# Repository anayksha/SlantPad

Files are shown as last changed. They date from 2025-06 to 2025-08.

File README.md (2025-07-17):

# SlantPad
So this is a really interesting looking macropad that I will primarily be using to CAD on Onshape.

The most distinctive feature is that the OLED and rotary encoder are mounted on the front at an angle
and will be attached to the PCB by soldering wires from the PCB to the components.

**Note:** I took heavy inspiration from Sam Liu's [Square Pad](https://github.com/samdev-7/squarepad/tree/main).

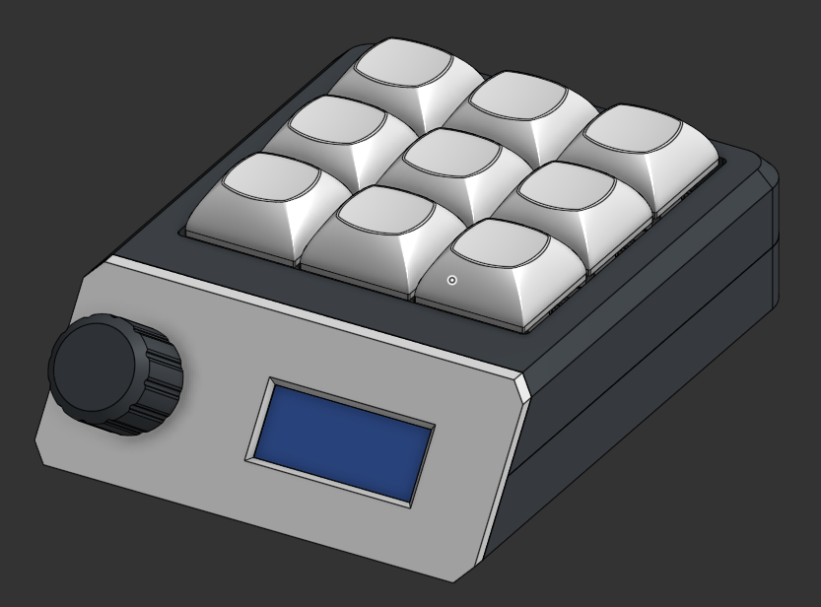
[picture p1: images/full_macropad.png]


## CAD
The case was modeled in Onshape and can be viewed [here](https://cad.onshape.com/documents/7421df7f1bb1a5a27283fec0/w/9a583cf50c19ed7cba38c083/e/84af72cc664b6b6948a7a570).

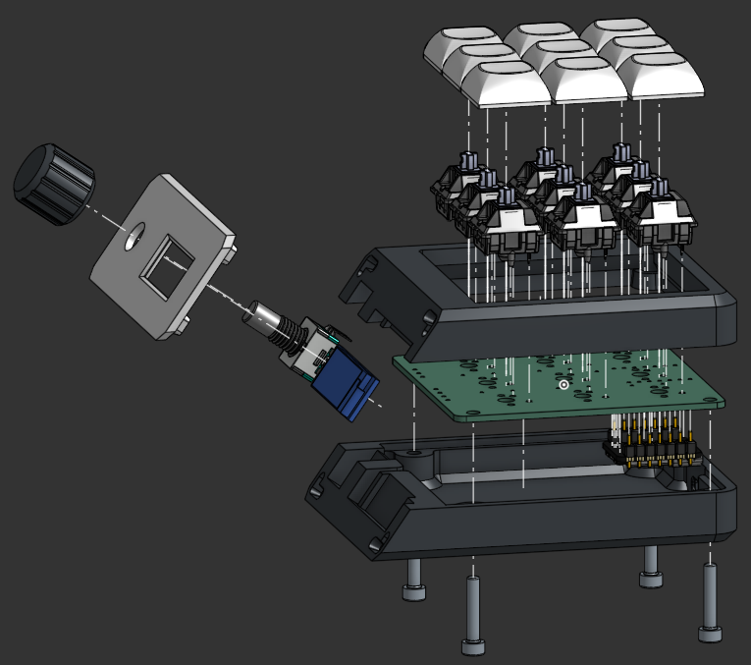
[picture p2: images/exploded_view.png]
<br><br>

Behind the front cover of the case, there are slots in both the bottom and top parts that allow the rotary encoder
and screen to fit.

There are 2 holes on the sides of the slot for the EC11, this so that the mounting pins on the
EC11 can be pushed in and it can be snapped into place. There are 2 other pins on the EC11 for the onboard
button, but I will be cutting those off because I am not using them.

There is a deeper rectanglular slot in the slot for the OLED, and this is so that the components on the back of the
OLED's PCB can fit. A channel on the side of the OLED slot leading to the main chamber of the case will allow wires to
go through from the OLED to the main PCB.

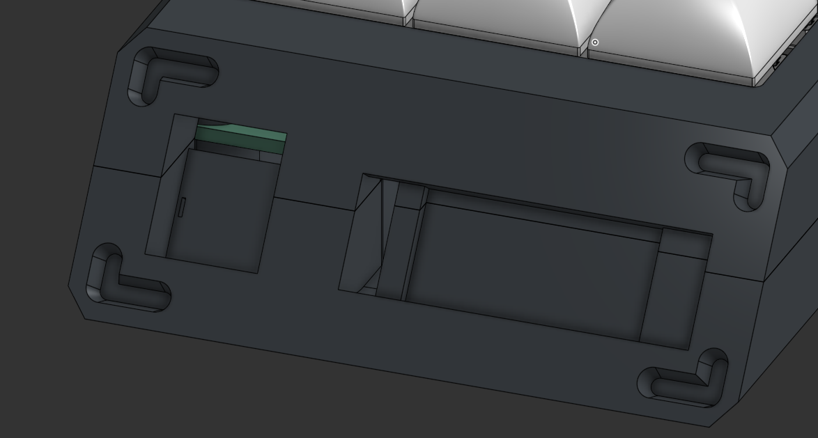
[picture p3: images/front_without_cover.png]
<br><br>

*The L shaped slots in the corners have corresponding protrusions in the front cover that make it easier to line up and
glue the front cover on*

***Why I am permanently mounting the front cover on:** I couldn't figure out how to screw the front cover on bc
heatset inserts take up a lot of space and there's like no space at the front and I havent made a
snap fit 3D print before and I thought that now is **not** the time to mess with clearances.*

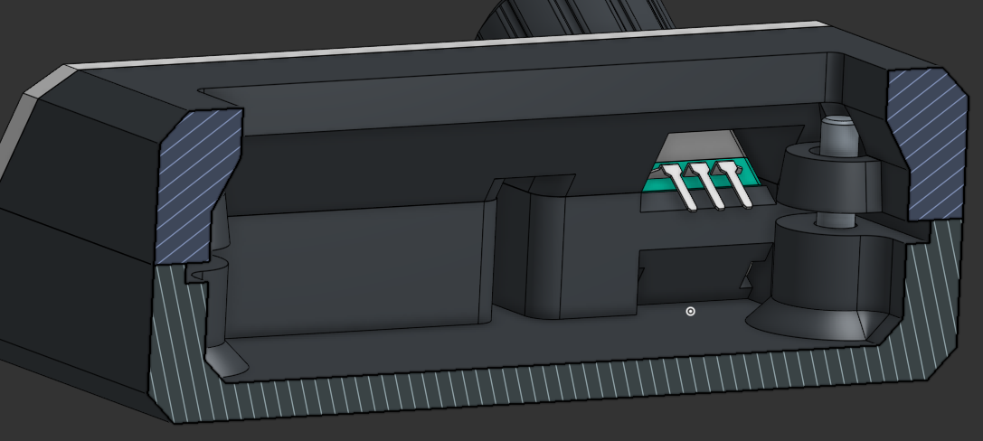
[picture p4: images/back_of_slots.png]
<br><br>

Also, I will probably be bending 3 main pins of the EC11 with pliers so they fit better in the case.

## PCB
Unfortunately I can't make a clean pcb for my life and I couldn't figure out how to connect everything without
excessively spamming vias and then via stitching the ground planes together on top of that.

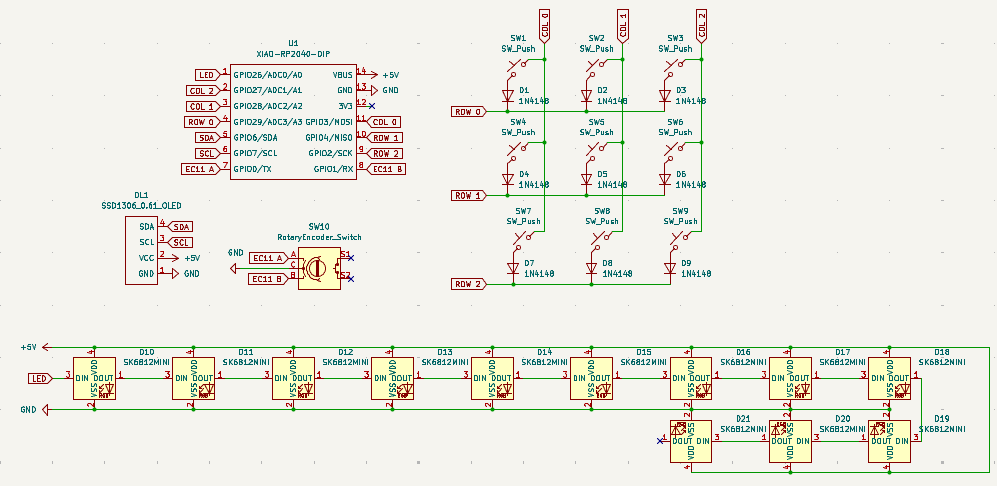
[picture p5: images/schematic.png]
<br><br>

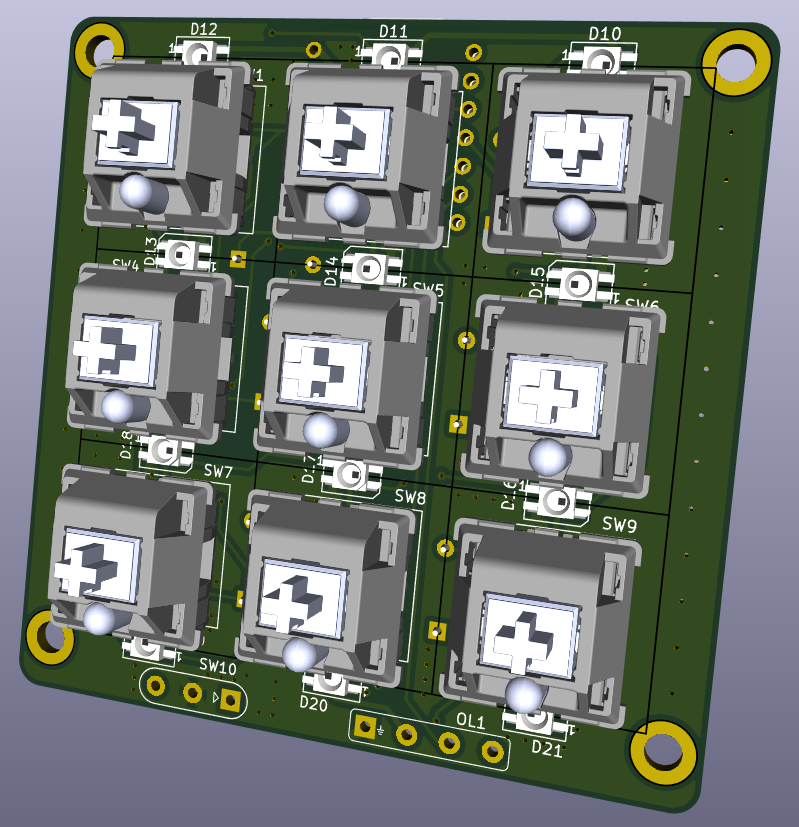
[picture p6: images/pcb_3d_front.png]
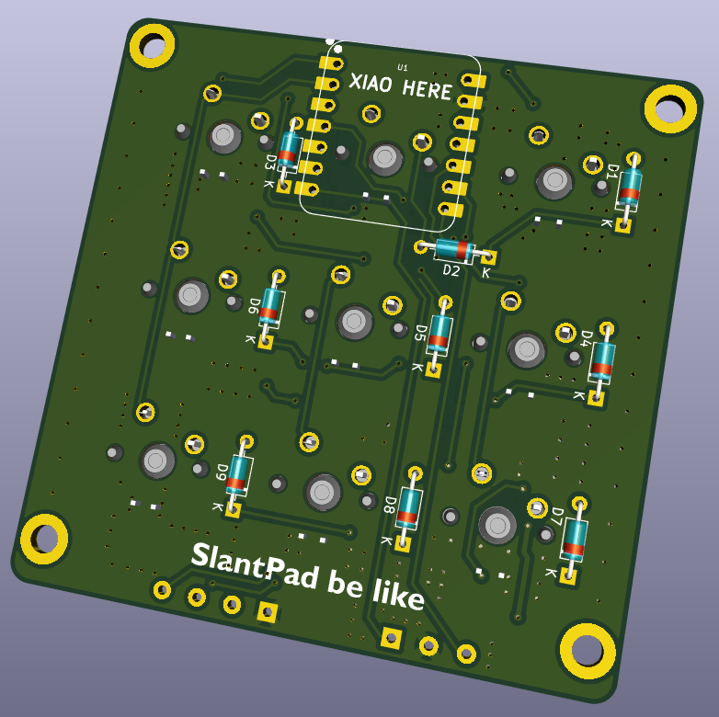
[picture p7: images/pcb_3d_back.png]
<br> <br>

*The XIAO RP2040 will be soldered to the back with header pins on.*

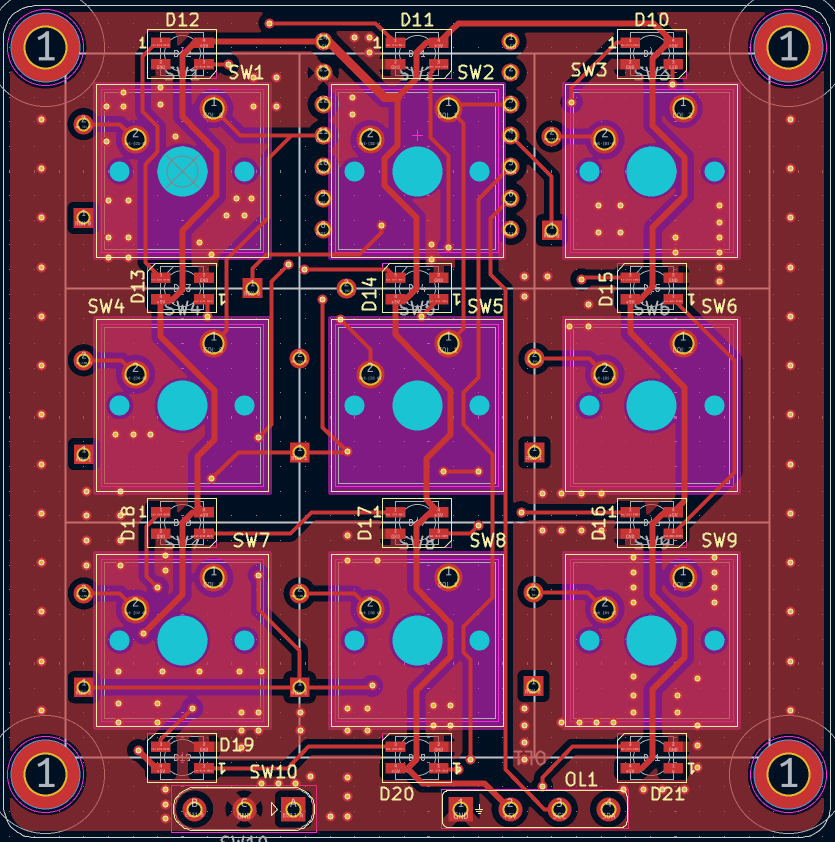
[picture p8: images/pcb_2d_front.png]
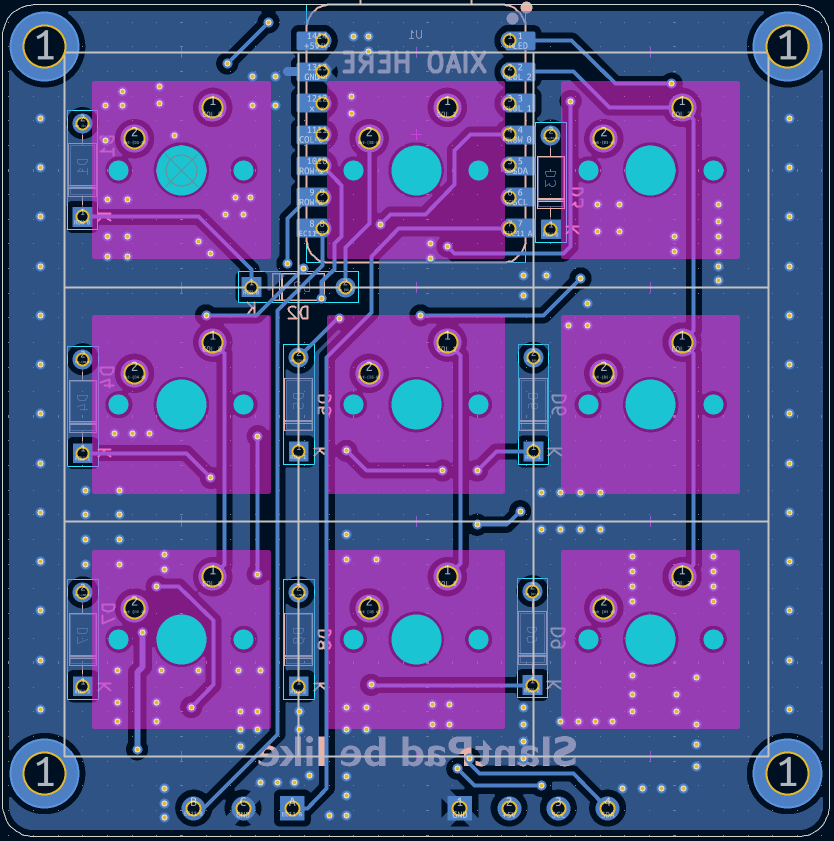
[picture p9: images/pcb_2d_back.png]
<br> <br>

## BOM
* 1x SEEED XIAO RP2040
* 9x Cherry MX Switches
* 9x DSA Keycaps
* 9x 1N4148 THT Diodes
* 12x SK6812 MINI-E LEDs
* 1x EC11 Rotary Encoder
* 1x 0.91" OLED Display
* 4x M3x16mm screws
* 4x M3x5mmx4mm heatset inserts
* 1x Case (3x 3D printed parts)
* 1x Knob (3D printed)
* wires (i will source those myself)

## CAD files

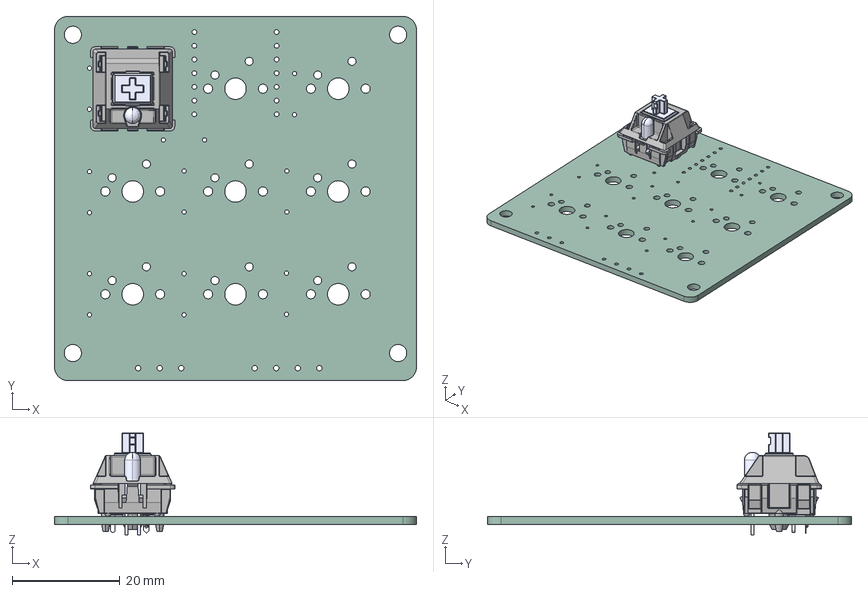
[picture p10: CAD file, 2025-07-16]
CAD/3D Assets/SlantPad pcb model.step
67.1 x 67.5 x 18.9 mm
MX Öá °´¼ü¡ä_¨¹___¡§1
MX ס סͥ¨¢¨¬_¡§¡顧__
MXס ϞñLEDLEDLED
MXÖá ÖáÌå µ×²¿ ¦Ì¡Á2__Ä¬ÈÏ_¨¢2____¨¨_
֫½ğ__Ĭɏ__¨¨_
CADPad_PCB

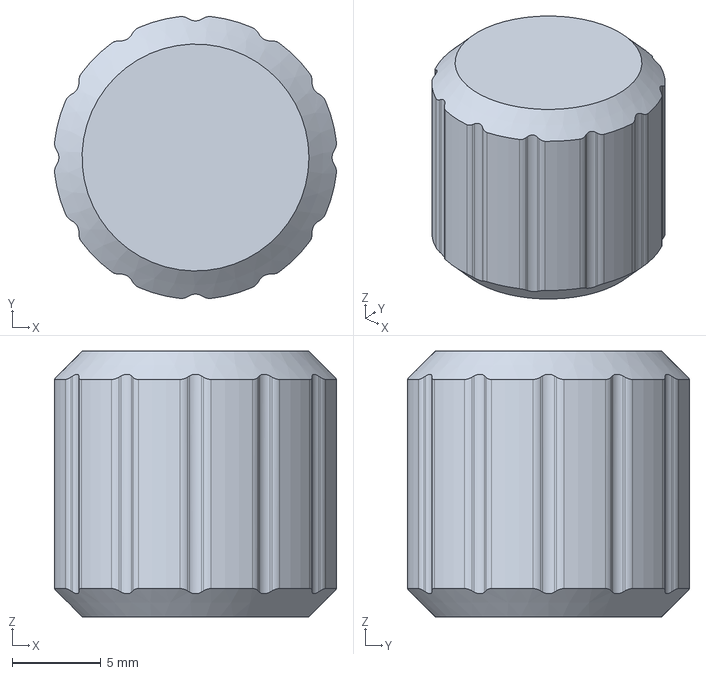
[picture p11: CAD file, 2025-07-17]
Production/knob.step
15.9 x 15.9 x 15.0 mm

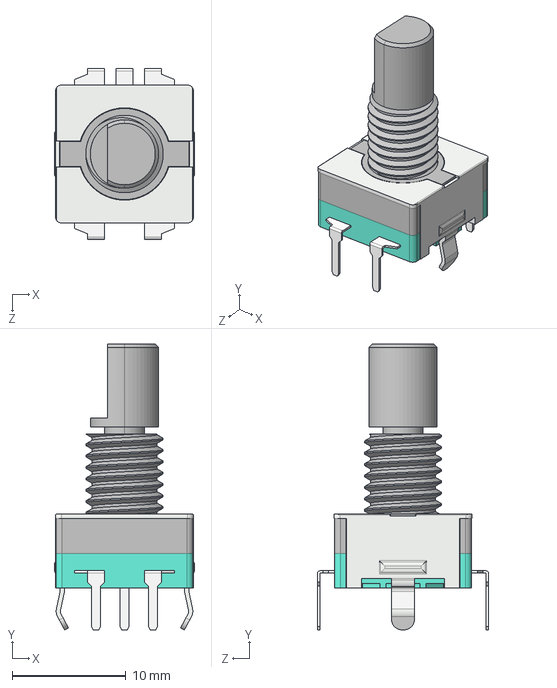
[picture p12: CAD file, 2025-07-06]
CAD/3D Assets/EC11 Rotary Encoder.STEP
12.3 x 25.1 x 15.0 mm

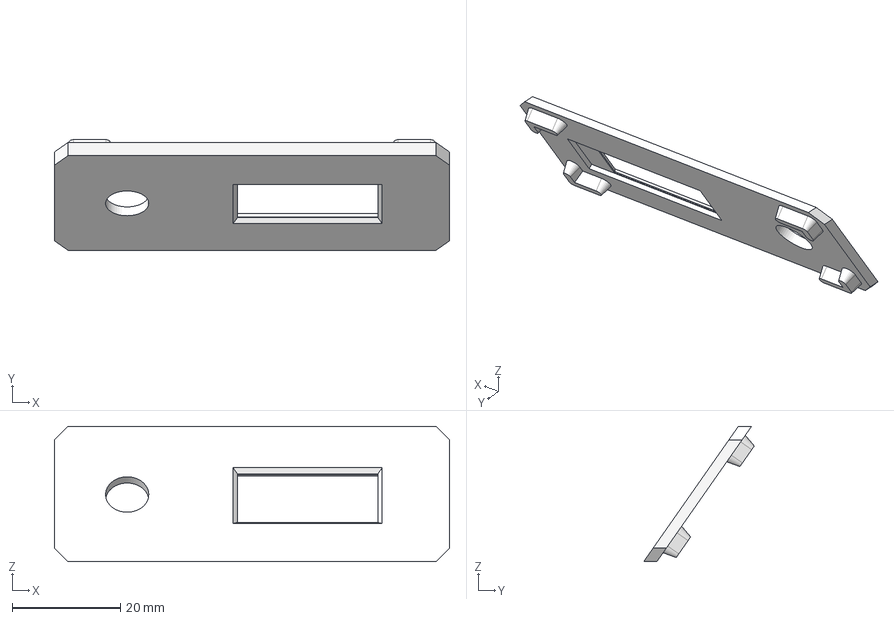
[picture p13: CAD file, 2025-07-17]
Production/front cover.step
73.1 x 20.5 x 25.0 mm

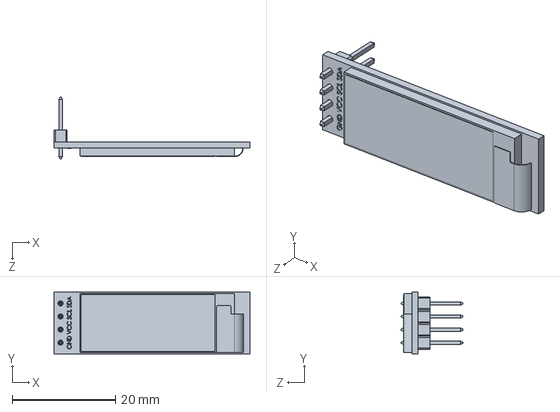
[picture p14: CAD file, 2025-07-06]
CAD/3D Assets/SSD1306_0.91_OLED.STEP
38.0 x 12.0 x 11.9 mm

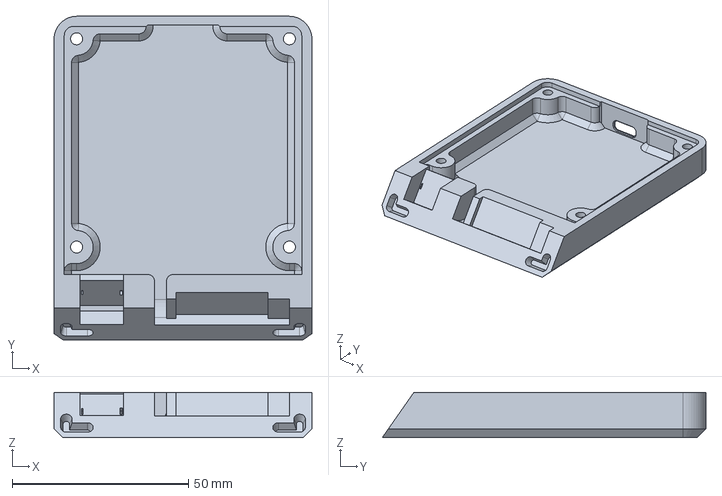
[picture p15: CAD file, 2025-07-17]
Production/case bottom.step
73.1 x 91.7 x 12.8 mm

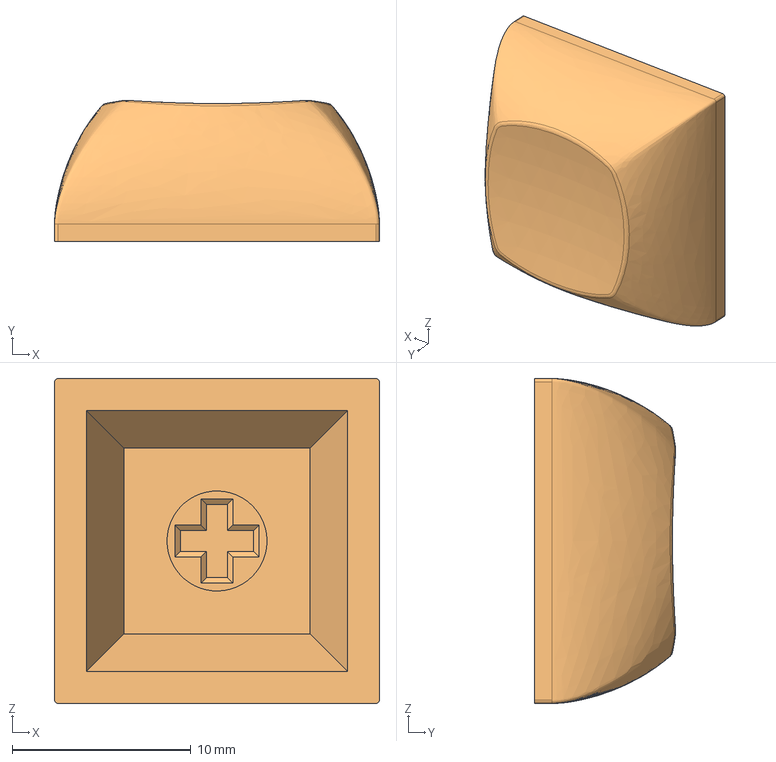
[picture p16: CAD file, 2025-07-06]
CAD/3D Assets/DSA_1u.step
18.2 x 7.91 x 18.2 mm

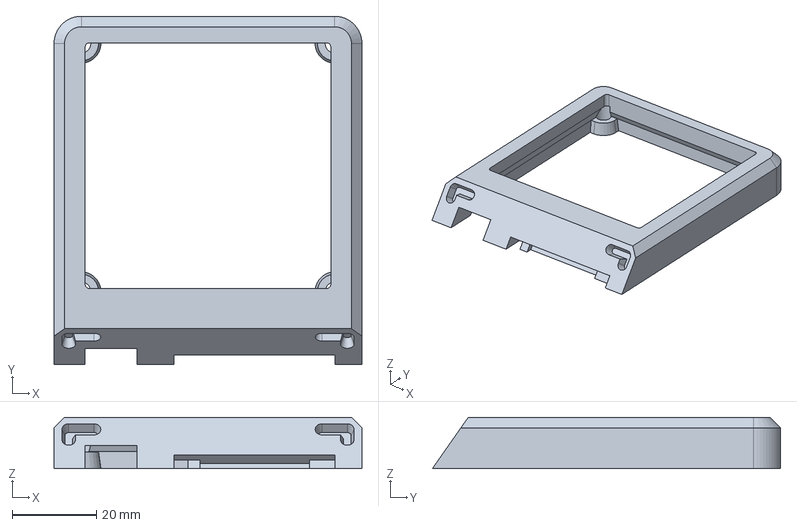
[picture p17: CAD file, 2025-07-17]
Production/case top.step
73.1 x 82.7 x 12.2 mm

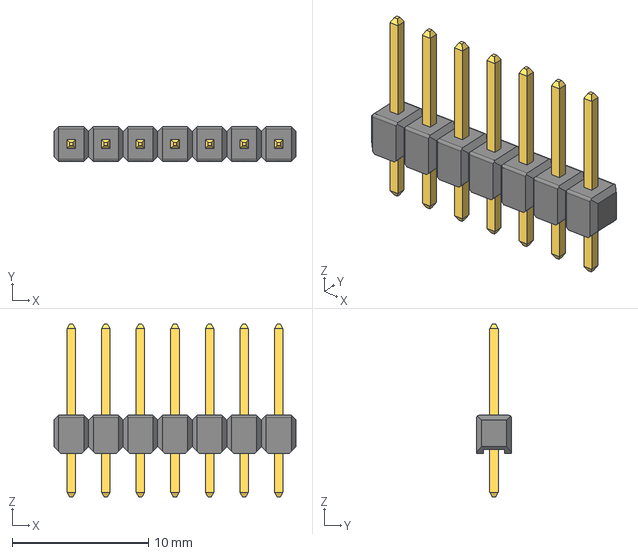
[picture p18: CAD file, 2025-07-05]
CAD/3D Assets/Pin Header 1x7 TH Pitch 2.54mm.stp
17.8 x 2.54 x 12.7 mm

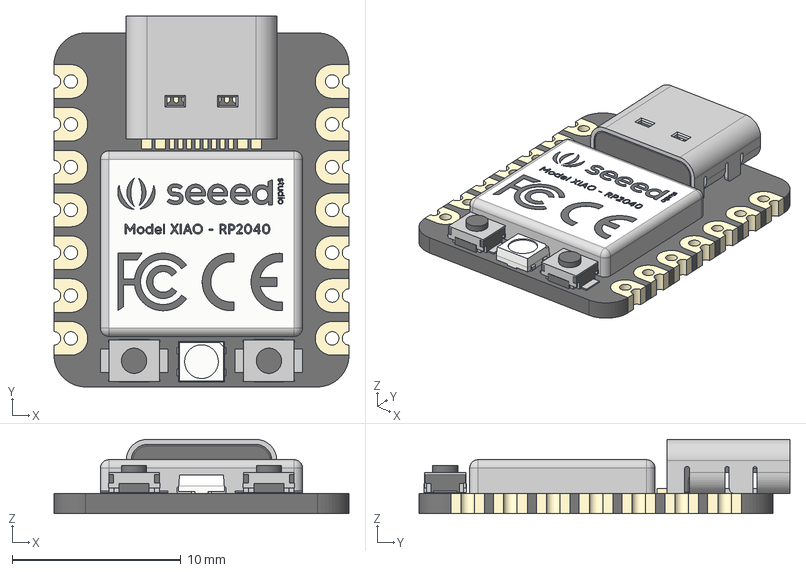
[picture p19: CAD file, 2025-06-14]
CAD/3D Assets/Seeed Studio XIAO RP2040 v26.step
17.5 x 22.0 x 4.40 mm
type-c v2
smd_button v3
DOUT
DIN
VSS
VDD
smd_button v3(Mirror)

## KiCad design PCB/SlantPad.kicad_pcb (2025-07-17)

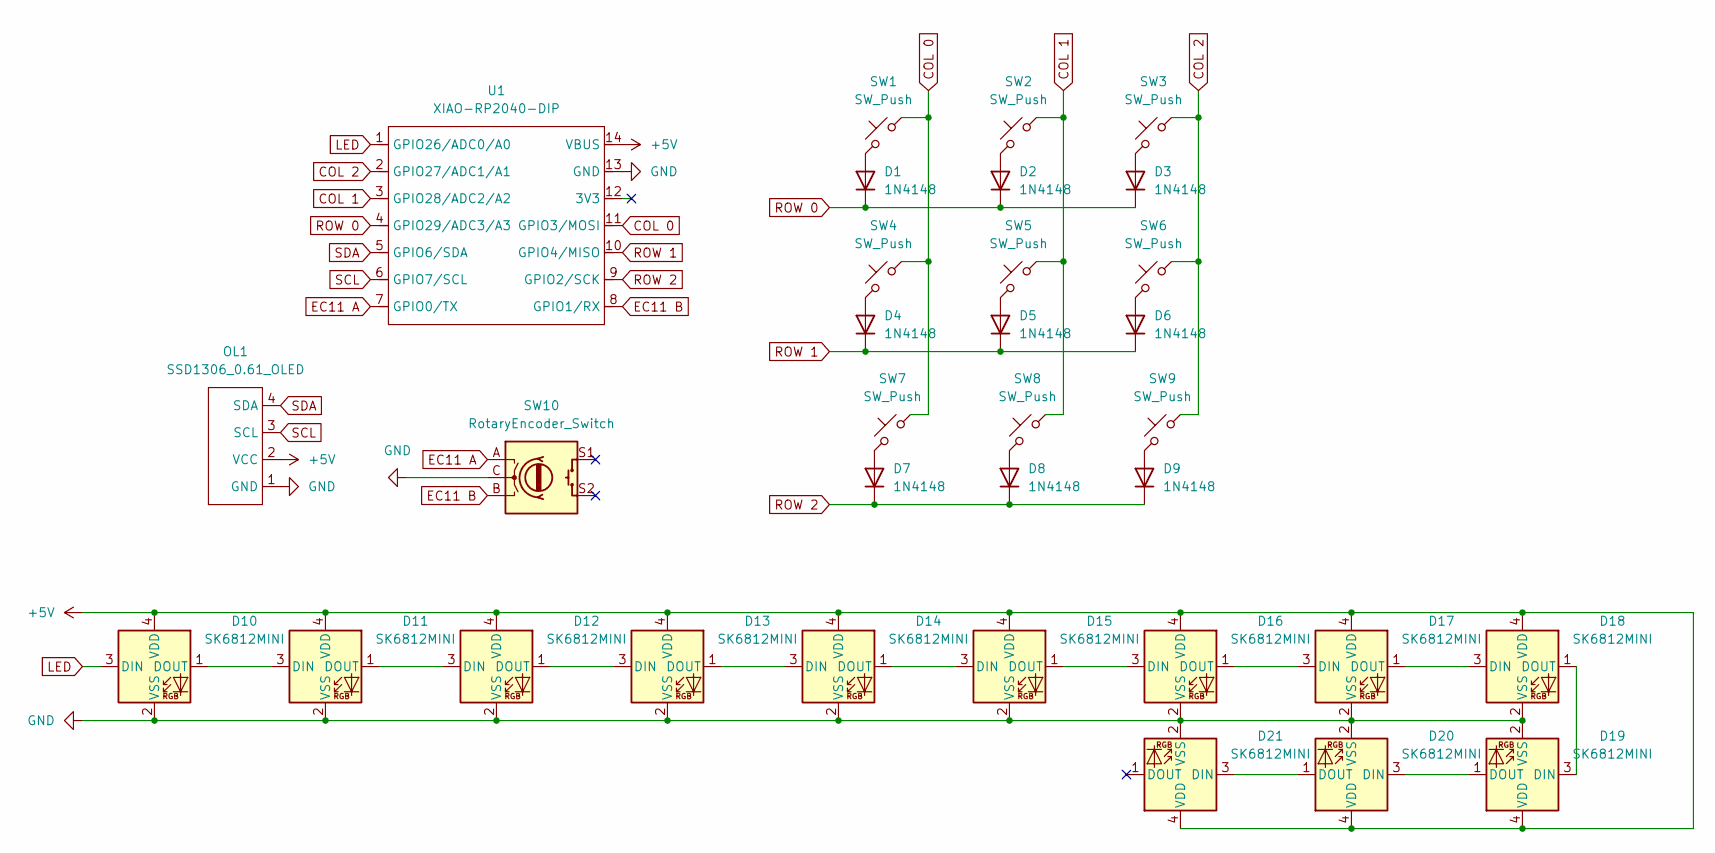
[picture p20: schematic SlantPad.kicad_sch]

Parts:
D1, D2, D3, D4, D5, D6, D7, D8, D9: 1N4148; D_DO-35_SOD27_P7.62mm_Horizontal
D10, D11, D12, D13, D14, D15, D16, D17, D18, D19, D20, D21: SK6812MINI; LED_SK6812MINI_PLCC4_3.5x3.5mm_P1.75mm
OL1: SSD1306_0.61_OLED; SSD1306_0.91_OLED_Wire_Connector
SW1, SW2, SW3, SW4, SW5, SW6, SW7, SW8, SW9: SW_Push; SW_Cherry_MX_1.00u_PCB
SW10: RotaryEncoder_Switch; Rotary_Encoder_Wire_Connector
U1: XIAO-RP2040-DIP

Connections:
+5V: D10.4 (VDD), D11.4 (VDD), D12.4 (VDD), D13.4 (VDD), D14.4 (VDD), D15.4 (VDD), D16.4 (VDD), D17.4 (VDD), D18.4 (VDD), D19.4 (VDD), D20.4 (VDD), D21.4 (VDD), OL1.2 (VCC), U1.14 (VBUS)
COL 0: SW1.1, SW4.1, SW7.1, U1.11 (GPIO3/MOSI)
COL 1: SW2.1, SW5.1, SW8.1, U1.3 (GPIO28/ADC2/A2)
COL 2: SW3.1, SW6.1, SW9.1, U1.2 (GPIO27/ADC1/A1)
EC11 A: SW10.A, U1.7 (GPIO0/TX)
EC11 B: SW10.B, U1.8 (GPIO1/RX)
GND: D10.2 (VSS), D11.2 (VSS), D12.2 (VSS), D13.2 (VSS), D14.2 (VSS), D15.2 (VSS), D16.2 (VSS), D17.2 (VSS), D18.2 (VSS), D19.2 (VSS), D20.2 (VSS), D21.2 (VSS), OL1.1 (GND), SW10.C, U1.13 (GND)
LED: D10.3 (DIN), U1.1 (GPIO26/ADC0/A0)
unnamed: D1.2 (A), SW1.2
unnamed: D2.2 (A), SW2.2
unnamed: D3.2 (A), SW3.2
unnamed: D4.2 (A), SW4.2
unnamed: D5.2 (A), SW5.2
unnamed: D6.2 (A), SW6.2
unnamed: D7.2 (A), SW7.2
unnamed: D8.2 (A), SW8.2
unnamed: D9.2 (A), SW9.2
unnamed: D10.1 (DOUT), D11.3 (DIN)
unnamed: D11.1 (DOUT), D12.3 (DIN)
unnamed: D12.1 (DOUT), D13.3 (DIN)
unnamed: D13.1 (DOUT), D14.3 (DIN)
unnamed: D14.1 (DOUT), D15.3 (DIN)
unnamed: D15.1 (DOUT), D16.3 (DIN)
unnamed: D16.1 (DOUT), D17.3 (DIN)
unnamed: D17.1 (DOUT), D18.3 (DIN)
unnamed: D18.1 (DOUT), D19.3 (DIN)
unnamed: D19.1 (DOUT), D20.3 (DIN)
unnamed: D20.1 (DOUT), D21.3 (DIN)
ROW 0: D1.1 (K), D2.1 (K), D3.1 (K), U1.4 (GPIO29/ADC3/A3)
ROW 1: D4.1 (K), D5.1 (K), D6.1 (K), U1.10 (GPIO4/MISO)
ROW 2: D7.1 (K), D8.1 (K), D9.1 (K), U1.9 (GPIO2/SCK)
SCL: OL1.3 (SCL), U1.6 (GPIO7/SCL)
SDA: OL1.4 (SDA), U1.5 (GPIO6/SDA)

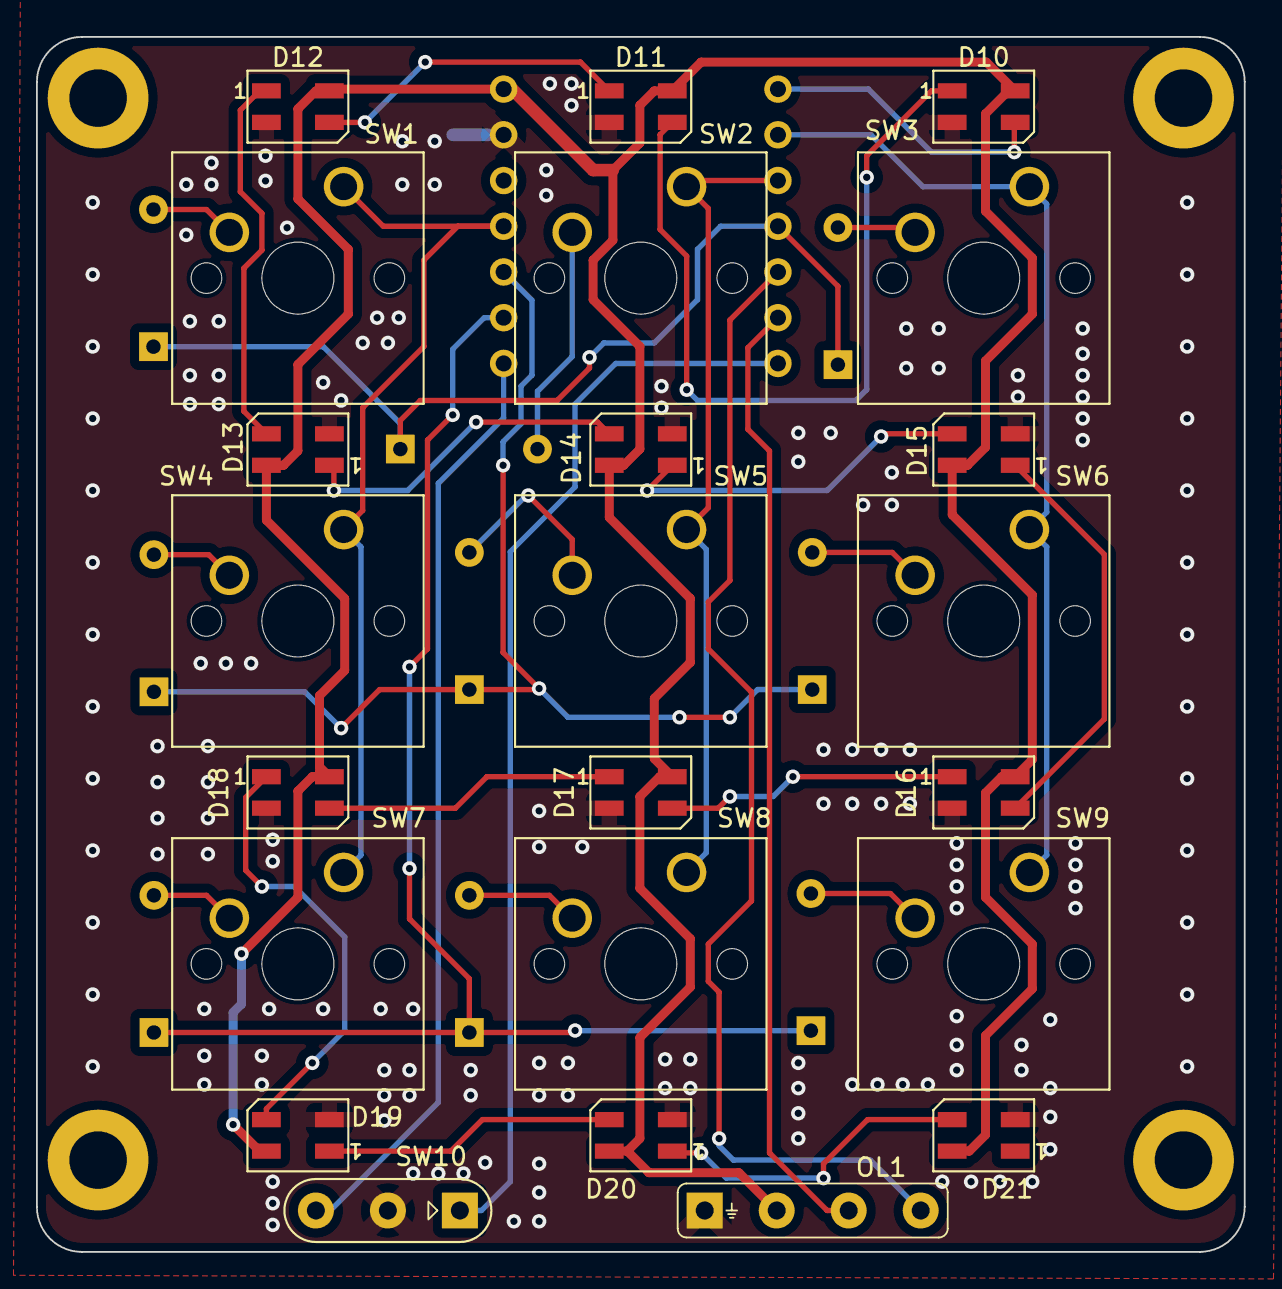
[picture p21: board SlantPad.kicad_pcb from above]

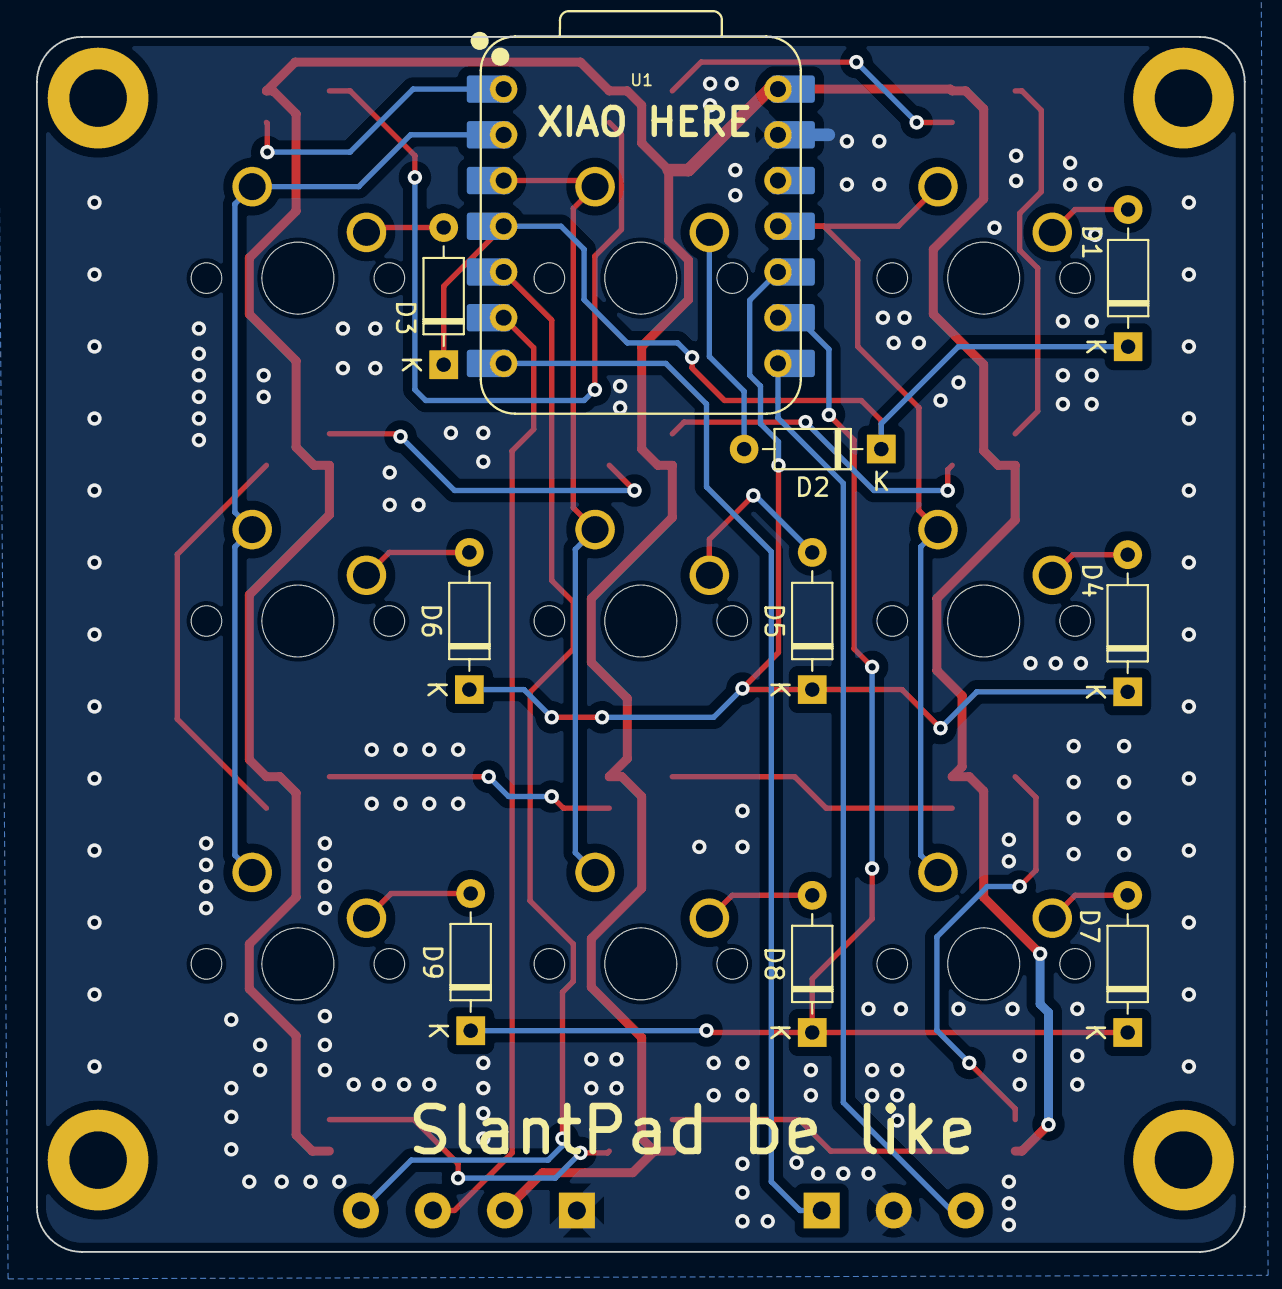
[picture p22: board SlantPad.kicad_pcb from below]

Board: 2 copper layers, 67.1 x 67.5 mm, 33 parts (10 on the bottom side), 33 nets.

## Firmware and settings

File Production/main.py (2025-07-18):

'''
TODO: explain that this allows u to swap between diff keybinds for diff onshape modes
'''
import board
import busio

from kmk.kmk_keyboard import KMKKeyboard
from kmk.keys import KC
from kmk.scanners import DiodeOrientation
from kmk.modules.encoder import EncoderHandler
from kmk.modules.macros import Macros
from kmk.extensions.rgb import RGB, AnimationModes # remember to install NeoPixel library
from kmk.extensions.display import Display, TextEntry, ImageEntry # remember to install adafruit_display_text
from kmk.extensions.display.ssd1306 import SSD1306 # remember to install adafruit_displayio_ssd1306

from pad_profiles import Profile, ProfileSwitcher

# idk abt the specific keybinds ill figure them out later
PS_PROFILE = Profile(
    [[KC.NO, KC.NO, KC.NO],
     [KC.NO, KC.NO, KC.NO],
     [KC.NO, KC.NO, KC.NO]],
    (30, 247, 50),
    AnimationModes.BREATHING,
    []
)
SKETCH_PROFILE = Profile(
    [[KC.NO, KC.NO, KC.NO],
     [KC.NO, KC.NO, KC.NO],
     [KC.NO, KC.NO, KC.NO]],
    (56, 247, 50),
    AnimationModes.BREATHING,
    []
)
CONSTRAINT_PROFILE = Profile(
    [[KC.NO, KC.NO, KC.NO],
     [KC.NO, KC.NO, KC.NO],
     [KC.NO, KC.NO, KC.NO]],
    (141, 250, 50),
    AnimationModes.BREATHING,
    []
)
ASM_PROFILE = Profile(
    [[KC.NO, KC.NO, KC.NO],
     [KC.NO, KC.NO, KC.NO],
     [KC.NO, KC.NO, KC.NO]],
    (9, 217, 50),
    AnimationModes.BREATHING,
    []
)
STEP_SIZE = 2


profile_switcher = ProfileSwitcher([PS_PROFILE, SKETCH_PROFILE, CONSTRAINT_PROFILE, ASM_PROFILE], STEP_SIZE)

keyboard = KMKKeyboard()
keyboard.col_pins = (board.D10, board.D2, board.D1)
keyboard.row_pins = (board.D3, board.D9, board.D8)
keyboard.diode_orientation = DiodeOrientation.COL2ROW

encoder_handler = EncoderHandler()
keyboard.modules.append(encoder_handler)
encoder_handler.pins = (board.D6, board.D7, None)

keyboard.modules.append(Macros())

rgb = RGB(pixel_pin=board.D0, num_pixels=12, val_default=50, val_limit=50, rgb_order=(1,0,2))
rgb.animation_mode = AnimationModes.BREATHING_RAINBOW
keyboard.extensions.append(rgb)

i2c_bus = busio.I2C(board.GP_SCL, board.GP_SDA)
display_driver = SSD1306(i2c=i2c_bus)
display = Display(display=display_driver, width=128, height=32)
display.entries = [TextEntry(text="Hello There", x=64, y=16, x_anchor="M", y_anchor="M")]
keyboard.extensions.append(display)


def switch_left_profile():
    switch_profile = profile_switcher.step_left()

    if switch_profile:
        profile = profile_switcher.curr_profile
        keyboard.keymap = profile.keymap
        rgb.set_hsv_fill(*profile.color)
        rgb.animation_mode = profile.anim_mode
        display.entries = profile.scrn_elements


def switch_right_profile():
    switch_profile = profile_switcher.step_right()

    if switch_profile:
        profile = profile_switcher.curr_profile
        keyboard.keymap = profile.keymap
        rgb.set_hsv_fill(*profile.color)
        rgb.animation_mode = profile.anim_mode
        display.entries = profile.scrn_elements


keyboard.keymap = profile_switcher.curr_profile.keymap

ENC_LEFT = KC.MACRO(switch_left_profile)
ENC_RIGHT = KC.MACRO(switch_right_profile)

encoder_handler.map = [((ENC_LEFT, ENC_RIGHT, KC.NO))]

if __name__ == "__main__":
    keyboard.go()

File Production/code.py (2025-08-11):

'''
TODO: explain that this allows u to swap between diff keybinds for diff onshape modes
'''
import board # type: ignore
import busio # type: ignore

from kmk.kmk_keyboard import KMKKeyboard
from kmk.keys import KC
from kmk.scanners import DiodeOrientation
from kmk.modules.encoder import EncoderHandler
from kmk.modules.macros import Macros
from kmk.extensions.display import Display, TextEntry, ImageEntry # remember to install adafruit_display_text
from kmk.extensions.display.ssd1306 import SSD1306 # remember to install adafruit_displayio_ssd1306
from kmk.extensions.media_keys import MediaKeys

from pad_profiles import Profile, ProfileSwitcher


keyboard = KMKKeyboard()
encoder_handler = EncoderHandler()
i2c_bus = busio.I2C(board.D5, board.D4)
display_driver = SSD1306(i2c=i2c_bus)
display = Display(display=display_driver, width=128, height=32)

keyboard.col_pins = (board.D10, board.D2, board.D1)
keyboard.row_pins = (board.D3, board.D9, board.D8)
keyboard.diode_orientation = DiodeOrientation.COL2ROW
encoder_handler.pins = ((board.D6, board.D7, None))

keyboard.modules.extend([encoder_handler, Macros()])
keyboard.extensions.extend([display, MediaKeys()])


# idk abt the specific keybinds ill figure them out later
# idk why i chose microsoft colors but they're good placeholder ig
MEDIA_PROFILE = Profile(
    [[
        KC.MPRV, KC.MSTP, KC.MNXT,
        KC.MRWD, KC.MPLY, KC.MFFD,
        KC.VOLD, KC.MUTE, KC.VOLU
    ]],
    [
        TextEntry("media controls be like", 64, 16, x_anchor="M", y_anchor="M")
    ]
)
PS_PROFILE = Profile(
    [[
        KC.N1, KC.N1, KC.N1,
        KC.N1, KC.N1, KC.N1,
        KC.N1, KC.N1, KC.N1
    ]],
    [
        TextEntry("part studio be like", 64, 16, x_anchor="M", y_anchor="M"),
    ]
)
SKETCH_PROFILE = Profile(
    [[
        KC.N2, KC.N2, KC.N2,
        KC.N2, KC.N2, KC.N2,
        KC.N2, KC.N2, KC.N2
    ]],
    [
        TextEntry("sketch be like", 64, 16, x_anchor="M", y_anchor="M")
    ]
)
CONSTRAINT_PROFILE = Profile(
    [[
        KC.N3, KC.N3, KC.N3,
        KC.N3, KC.N3, KC.N3,
        KC.N3, KC.N3, KC.N3
    ]],
    [
        TextEntry("constraint be like", 64, 16, x_anchor="M", y_anchor="M")
    ]
)
ASM_PROFILE = Profile(
    [[
        KC.N4, KC.N4, KC.N4,
        KC.N4, KC.N4, KC.N4,
        KC.N4, KC.N4, KC.N4
    ]],
    [
        TextEntry("assembly be like", 64, 16, x_anchor="M", y_anchor="M")
    ]
)
STEP_SIZE = 2

profile_switcher = ProfileSwitcher([MEDIA_PROFILE, PS_PROFILE, SKETCH_PROFILE, CONSTRAINT_PROFILE, ASM_PROFILE], STEP_SIZE)


def switch_left_profile():
    switch_profile = profile_switcher.step_left()

    if switch_profile:
        profile = profile_switcher.curr_profile
        keyboard.keymap = profile.keymap
        display.entries = profile.scrn_elements


def switch_right_profile():
    switch_profile = profile_switcher.step_right()

    if switch_profile:
        profile = profile_switcher.curr_profile
        keyboard.keymap = profile.keymap
        display.entries = profile.scrn_elements

init_profile = profile_switcher.curr_profile
keyboard.keymap = init_profile.keymap
display.entries = init_profile.scrn_elements

ENC_LEFT = KC.MACRO(switch_left_profile)
ENC_RIGHT = KC.MACRO(switch_right_profile)

encoder_handler.map = [((ENC_LEFT, ENC_RIGHT, KC.NO))]

if __name__ == "__main__":
    keyboard.go()

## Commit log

2025-06-13 created kicad project
    [CADPad.kicad_pcb, CADPad.kicad_sch]
2025-06-13 mostly finished schematic
    [CADPad.kicad_sch]
2025-06-14 started pcb
    [CADPad.kicad_pcb, CADPad.kicad_sch]
2025-06-14 made general layout on pcb
    [CADPad.kicad_pcb, CADPad.kicad_sch]
2025-06-14 traced almost everything
    [CADPad.kicad_pcb, CADPad.kicad_sch]
2025-06-14 final board layout?
    [CADPad.kicad_pcb]
2025-06-27 arranged everything; before ground pour
    [CADPad.kicad_pcb]
2025-06-27 finished pcb
    [CADPad.kicad_pcb, bom.csv, designators.csv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]
2025-07-05 managed pcb models and started cadding
    [CADPad pcb model.step, CADPad.kicad_pcb, Pin Header 1x7 TH Pitch 2.54mm.stp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]
2025-07-06 shortened pcb
    [CADPad pcb model.step, CADPad.kicad_pcb, DSA_1u.step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]
2025-07-16 spaced mounting holes farther from switches
    [CADPad pcb model V2.step, CADPad.kicad_pcb]
2025-07-17 renamed everything lol
    [CADPad pcb model.step, SlantPad pcb model.step, SlantPad.kicad_pcb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]
2025-07-17 added production files
    [case bottom.step, case top.step, front cover.step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]
2025-08-07 no backlighting 😔 alr ordered pcb and apparently used wrong neopixel footprint
    [SlantPad.kicad_sch]
2025-08-11 MEDIA STUFF 🥳🥳 bro why'd i try to implement media on my own WHEN THERES AN EXTENSION 😭
